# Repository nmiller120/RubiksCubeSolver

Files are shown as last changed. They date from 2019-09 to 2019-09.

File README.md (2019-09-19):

# Automated Rubiks Cube Solver

Ongoing work-in-progress. Goal is to design a system that is able to grab and automatically solve a Rubik's Cube after reading the colors off of the cube via a webcam. A demonstration of the mechanical portion of the build can be seen via the following youtube link: https://www.youtube.com/watch?v=32NWT3KxtNk. A demonstration of the color calibration utility can be seen here: https://www.youtube.com/watch?v=5z36a5fC41Q

## Mechanical Design

Parts were designed in Autodesk Inventor, the cross sections of the parts were copied into Autocad and laid out on a single sheet. The file was exported again this time as a .dxf file. This file was then sent to Ponoko to be lasercut.

The actuators are all standard size hobby servo motors, primarily used in RC cars. They are cheap, fairly powerful, and easy to control.

## Electrical Design

The Arduino acts as the controller for the servo motor assembly. It interfaces with a servo motor driver board to control the 8 servos. The arduino recieves serial commands from the program running on my laptop via USB. These commands are decoded into smaller instructions that are passed down to ther servo driver.

## Software Design

The goal of the project is to have the program start by moving the assembly, showing the layout of the cube to a webcam mounted above. A computer vision algorithm is to be applied to the video feed, detecting the colors on the cube's faces and recording that data into memory. Once all of the faces have been read, the data recorded is to be passed to the Kociemba algorithm. The algorithm outputs instructions on how the cube is to be solved. The AssemblyController module then parses those instructions and determines how each of the given instructions is to be implemented and relays that information to the arduino by commanding the positioning of the assembly's servo motors. A demo of the mechanical assembly working a solution can be seen above, as well as a demo on how the HSV filtering values are calibrated.

I have spent a lot of time commenting and adding documentation to the code for this project. I am trying to keep the code in as readable of condition as possible. Feel free to read through the project files as they may shed light on some of the more of the technical details of the project not covered here. 

Thanks for reading!

### Additional Links:
Kociemba Algorithm: https://github.com/muodov/kociemba  
Open CV Library: https://pypi.org/project/opencv-python/

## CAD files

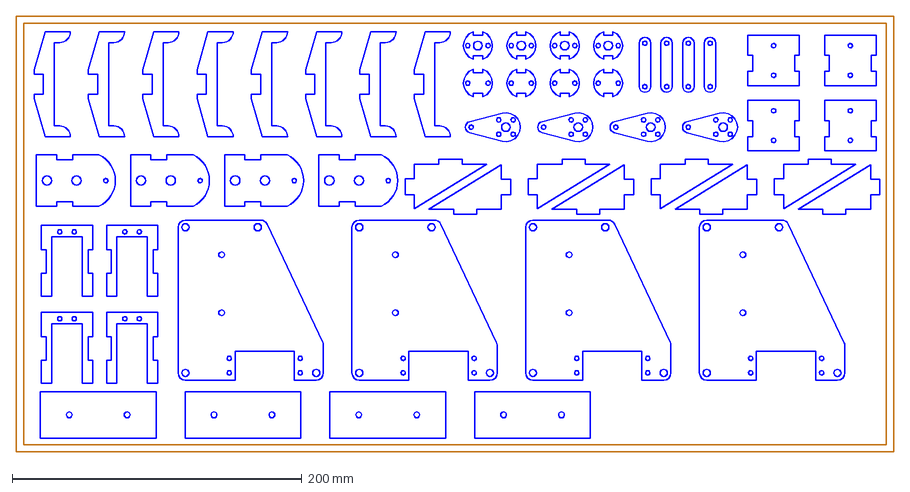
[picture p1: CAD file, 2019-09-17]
Rubiks_Cube_CAD_Design.dxf
606.0 x 301.0 mm

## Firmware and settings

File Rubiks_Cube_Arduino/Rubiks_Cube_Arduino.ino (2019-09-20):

 /**************************************************************************
 Code for the firmware running on the arduino for the rubiks cube project. The arduino acts as a controller for the assembly, 
 taking commands from the PC. The assembly begins in standby mode where it waits for a command.

  - In "Program" mode the arduino waits for the default positions of each of the servo motors to be loaded into the settingArray
  
  - In "calibration" mode the arduino accepts a continuous stream of commands for the positons of each of the servo motors. Unlike in 
  run mode these positions are a value between 0 and 180 allowing the servo motors to sit anywhere in their full range of motion. 
  This mode is used to determine the setpoints to be downloaded in "Program" mode and used in "run" mode.
  
  - In "run" mode the arduino accepts commands of the form "xYxYxY" where x represents any servo motor from 0 to 7 and Y represents a 
  pre-programmed position. This command can have between 2 and 16 characters.
  
  Example of run commands:
    - 012131 (servos 0, 1, and 3 to position 1)
    - 73 (servo 7 to position 3)
    - 4263 (servo 4 to position 2, servo 6 to position 3)

  The servo motors are divided into 2 groups, linear and radial. Linear moves the claws forward and backward, 
  radial servos rotate the claws. Even rows in the settingArray represent linear, odd rows represent radial. 
  
  Position 0, 1, and 2 for radial servos represent 0, 90 and 180 degrees respectively. 
  Positions 0 and 1 represent 45 and 135 degrees respectively. 
 */
#include <Wire.h>
#include <Adafruit_PWMServoDriver.h>

// called this way, it uses the default address 0x40
Adafruit_PWMServoDriver pwm = Adafruit_PWMServoDriver();

// constants defined to use in the calculation of the pulse width sent to the servo motor driver
#define MIN_PULSE_WIDTH       650
#define MAX_PULSE_WIDTH       2350
#define DEFAULT_PULSE_WIDTH   1500
#define FREQUENCY             50

int mode = 0; // 0:standby, 1:program, 2:run
String modeNames[4] = {"standby", "program", "run", "calibration"};
int error_check; // error check to send after programming, program should throw zero, if not there was an error
bool debug = false; // if true, print text to command line
int servoNumber; // servo number, use in run
int servoPos;  // servo position, use in run

char readByte;


int settingArray[8][6]; 
// settingArray: row is servo, col is position, even rows are linear, odd rows are radial
// linear goes 45 pos, 135 pos, 45+ pos, 135+ pos, dummy 90
// radial goes 0 pos, 90 pos, 180 pos, 0+ pos, 90+ pos

void setup(){
  // open serial port, begin communication with the servo driver
  Serial.begin(9600);
  Serial.print(mode);
  pwm.begin();
  pwm.setPWMFreq(FREQUENCY);  // Analog servos run at ~60 Hz update
}

void loop() {
  // main loop, 4 different modes of operation
  while (Serial.available()==0){}// wait for serial data
  if (mode == 2) {run_mode();} // if in run, run run 
  else if (mode == 3) {calibration();} // if in calibration mode, run calibration
  else if (mode == 0){standby();} //if in standby run standby
  else if(mode == 1){program();} // if in program mode run program 
}

void calibration(){
  /*
     Function reads a semi-continuous stream of data. Each calibration command is coded in ASCII text and is of the form
     1.x.x.x.x.x.x where 1 signals the start of a new command and each x is an integer between 0 and 180. The following code 
     parses those commands and writes them out to the motor controller using the setPWM() function. If a value of -10 is sent 
     to the arduino the assembly returns to standby mode
  */
  while(Serial.available()){
    int readIN = Serial.parseInt();
    if (readIN == 1){
      int servoPos[8];
      for(int i=0; i<8; i++){
        servoPos[i] = Serial.parseInt();
        pwm.setPWM(i, 0, pulseWidth(servoPos[i])); 
        }
      }
    else if (readIN == -10){changeMode(0);}
    }
  }

void run_mode(){
  /*    
    Function reads coded commands from the serial port and moves the motors to match the described positions. Motors 
    That aren't addressed in the command don't move. If the arduino recieves an invalid input the program returns to standby
     
    run mode serial commands: first character refers to the servo to control,
    2nd character refers to the position, ie, "0121" means servo 0 position 1, servo 2
    position 1. The positions are defined during the program phase, which is implemented
    in the code for the __init__() method of this class
  */
  int servoNumber;
  int servoPosition;

  while (Serial.available() < 2) {}
  servoNumber = Serial.read() - '0'; 
  servoPosition = Serial.read() - '0';
  
  if (servoNumber > 7 || servoNumber < 0) {changeMode(0);} // change mode if servo addressed is not in range
  
  if (mode == 2){ // if still in run mode, move servos and change output
    if (debug) {
      Serial.print('\n');
      Serial.print(servoNumber); Serial.print(' '); Serial.print(servoPosition);
      }
    int angle = settingArray[servoNumber][servoPosition];
    pwm.setPWM(servoNumber, 0, pulseWidth(angle));
    }
  }
  
void program(){
  /*
   * This function is how the default position values are loaded to the arduino. The software running on the PC sends the positioning 
   * data as a stream of bytes (ie. 180 is transmitted as a single byte with hex value 0xB4). These values are loaded into the 
   * settingArray. The setting array is a 2d array. Even rows in the array are controlling linear motion, odd rows in the array are 
   * controlling radial motion. 
   *
   * Format of linear = [deg45, deg135, 0, 0, 0, 90] // the 90 degree values act as an error check of the instruction
   * Format of radial = [deg0, deg90, deg180, 0, deg90+, deg180+] deg90+ and deg180+ are slightly more agressive turns to help 
   * allignment of the cube face when turning a side.
   * 
   * Automatically goes back to standby mode after program settings are recieved
   */
  
  while (Serial.available()){
      delay(1000); //give the buffer time to fill
      for (int i=0; i<8; i++){
        for (int j=0; j<6; j++){
          settingArray[i][j] = Serial.read(); // if in program mode load settingArray with data from serial buffer
          }
        }
      
        // error check = 0
        if (settingArray[0][5]==90 && settingArray[2][5]==90 && settingArray[4][5]==90 && settingArray[6][5]==90){error_check = true;} 
   
        if (debug == true){
          Serial.println("Recieved data..."); 
          for (int i=0; i<8; i++){
            for (int j=0; j<6; j++){
              Serial.print(settingArray[i][j]); // if in program mode load setting array with data from serial buffer
              Serial.print(',');               
              }
            Serial.print('\n');
          }
          if (error_check){Serial.println("No Error");} else {Serial.println("Error");}
        }   
        else {
          if (!debug && error_check){Serial.print('y');}
          else {Serial.print('n');}
          }
        changeMode(0);
  }
}

void standby(){
  /*
   * Standby mode waits for a mode change command. Command is a 5 character ascii string. Debug mode can also be toggled in standby. 
   * This just sends debug messsages to the serial port along with the acnowlegments that are sent when debug mode is off. 
   */
  
  char modeSelect[8] = "";
      Serial.readBytes(modeSelect, 5);
      if (!strcmp(modeSelect, "progm")){changeMode(1);} // set to program mode if "program" was recieved in the serial buffer
      else if (!strcmp(modeSelect, "runmd")){changeMode(2);} // set to run if "run" was recieved in the serial buffer
      else if (!strcmp(modeSelect, "check")){checkData();}
      else if (!strcmp(modeSelect, "calib")){changeMode(3);}
      
      else if (!strcmp(modeSelect, "debug")){ // toggle debugging
          if (debug) {
            debug = false;
            changeMode(0);
            } 
           else if (!debug){
              debug = true;
              Serial.print('\n');
              Serial.println("Debugging");
           }
        }  
      else mode = 0;
      while(Serial.available()){Serial.read();}//flush the port
}

void checkData(){
  /*
   * If a check command is recieved in standby mode, this function will write the currently stored settingArray to the serial port
   */
  Serial.println("Recieved data..."); 
  for (int i=0; i<8; i++){
    for (int j=0; j<6; j++){
      Serial.print(settingArray[i][j]); // if in program mode load setting array with data from serial buffer
      Serial.print(',');               
    }
    Serial.print('\n');
  }
  }

void changeMode(int newMode){
  // function invoked when a changemode command is recieved at the serial port
  mode = newMode;
  if (debug == true) {
    Serial.print("In ");
    Serial.print(modeNames[mode]);
    Serial.println(" mode");
    }
  else {Serial.print(mode);}
  }

int pulseWidth(int angle){
  // calculates the pulse width value needed to achieve the desired angle of the servo motor
  int pulse_wide, analog_value;
  pulse_wide   = map(angle, 0, 180, MIN_PULSE_WIDTH, MAX_PULSE_WIDTH);
  analog_value = int(float(pulse_wide) / 1000000 * FREQUENCY * 4096);
  return analog_value;
}

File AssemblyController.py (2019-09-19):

# Module defines a single class AssemblyController which handles all communication
# with the servo assembly.

# When solving the cube, first the controller object is created, then the kociemba
# SOLUTION string is passed to the class method kociemba(). This method parses
# the solution string and sends the arduino controlling the assembly a series of
# instruction codes describing the positions of the servo motors needed to solve
# the puzzle. The other class methods are all public and can be called as needed.

# run mode serial commands: first character refers to the servo to control,
# 2nd character refers to the position, ie, "0121" means servo 0 position 1, servo 2
# position 1. The positions are defined during the program phase, which is implemented
# in the code for the __init__() method of this class

import serial
import time

class AssemblyController():

    __Serial = None # serial port object
    __delay = 0.5 # time the system waits for the servomotors to get into position
    # before sending the next command

    def __init__(self):

        # create serial port obj.
        self.__Serial = serial.Serial('COM3',9600, timeout = 1)
        Serial = self.__Serial
        while Serial.in_waiting == 0: # wait for data to arrive at the port
            pass

        print(Serial.read()) # print byte from port

        Serial.write("progm".encode('utf-8')) # set arduino to program mode
        print(Serial.read()) # read response from arduino

         # load servo default position values from csv file
        csv_file = "servos.csv"
        aFile = open(csv_file, 'r') # open csv file in read mode

        toSend = ""
        for line in aFile:
            line = line.strip()
            csv_line = line.split(",")
            for x in range(6):
                toSend += chr(int(csv_line[x])) # read csv values into 'toSend'

        Serial.write(toSend) # write 'toSend' data to arduino

        while (Serial.in_waiting==0): # wait for response
            pass

        while (Serial.in_waiting): # read response
            print(Serial.read()) # print response

        Serial.write("runmd".encode("utf-8"))
        print(Serial.read())

    def rightCCW(self):
        # method rotates the entire cube about the right axis CCW
        delay = self.__delay
        Serial = self.__Serial
        self.all_engaged()
        time.sleep(delay)
        Serial.write('2161') #1
        time.sleep(delay)
        Serial.write('7131') #2
        time.sleep(delay)
        Serial.write('2060') #3
        time.sleep(delay)
        Serial.write('0141') #4
        time.sleep(delay)
        Serial.write('3072') #5
        time.sleep(delay)
        Serial.write('0040') #6
        time.sleep(delay)
        Serial.write('61') #7
        time.sleep(delay)
        Serial.write('70') #8
        time.sleep(delay*1.5)
        Serial.write('60') #9
        time.sleep(delay)

    def rightCW(self):
        # method rotates the entire cube about the right axis clockwise
        delay = self.__delay
        Serial = self.__Serial
        self.all_engaged()
        time.sleep(delay)
        Serial.write('2161') #1
        time.sleep(delay)
        Serial.write('7131') #2
        time.sleep(delay)
        Serial.write('2060') #3
        time.sleep(delay)
        Serial.write('0141') #4
        time.sleep(delay)
        Serial.write('3270') #5
        time.sleep(delay)
        Serial.write('0040') #6
        time.sleep(delay)
        Serial.write('21') #7
        time.sleep(delay)
        Serial.write('30') #8
        time.sleep(delay*1.5)
        Serial.write('20') #9
        time.sleep(delay)

    def frontCCW(self):
        # method rotates the entire cube about the front axis counter-clockwise
        delay = self.__delay
        Serial = self.__Serial
        self.all_engaged()
        time.sleep(delay)
        Serial.write('0141') #1
        time.sleep(delay)
        Serial.write('1151') #2
        time.sleep(delay)
        Serial.write('0040') #3
        time.sleep(delay)
        Serial.write('6121') #4
        time.sleep(delay)
        Serial.write('1052') #5
        time.sleep(delay)
        Serial.write('2060') #6
        time.sleep(delay)
        Serial.write('41') #7
        time.sleep(delay)
        Serial.write('50') #8
        time.sleep(delay*1.5)
        Serial.write('40') #9
        time.sleep(delay)

    def frontCW(self):
        # method rotates the entire cube about the front axis clockwise
        delay = self.__delay
        Serial = self.__Serial
        self.all_engaged()
        time.sleep(delay)
        Serial.write('0141') #1
        time.sleep(delay)
        Serial.write('1151') #2
        time.sleep(delay)
        Serial.write('0040') #3
        time.sleep(delay)
        Serial.write('6121') #4
        time.sleep(delay)
        Serial.write('1250') #5
        time.sleep(delay)
        Serial.write('2060') #6
        time.sleep(delay)
        Serial.write('01') #7
        time.sleep(delay)
        Serial.write('10') #8
        time.sleep(delay*1.5)
        Serial.write('00') #9
        time.sleep(delay)

    def all_retract(self):
        # method retracts all claws
        instruction = '0110213041506170'
        self.__Serial.write(instruction)

    def all_engaged(self):
        # method extends all claws
        instruction = '0010203040506070'
        self.__Serial.write(instruction)

    def kociemba(self, kociemba_string):
        # method implements the kociemba solution
        # Example of kociemba string:
        # "R' D2 R' U2 R F2 D B2 U' R F' U R2 D L2 D' B2 R2 B2 U' B2"

        sides = ['F', 'R', 'B', 'L', 'U', 'D']
        inst = kociemba_string.split(' ')
        size = len(inst)
        print(size)

        # for each instruction in array
        for x in range(size):
            rotation = None

            # if instruction has one character, mark for clockwise rotation
            if len(inst[x]) == 1:
                rotation = "CW"

            # if instruction is followed by a single quote, mark for counter
            # clockwise rotation
            elif inst[x][1] == '\'':
                rotation = "CCW"

            # if instruction is followed by a 2 mark for 2 clockwise rotations
            elif inst[x][1] == '2':
                rotation = "2CW"

            # if the instruction is for a face that is not on the top or bottom
            # turn the given face according to the direction found above
            for y in range(4):
                if inst[x][0] == sides[y]:
                    self.turn_face(y, rotation)

            # if the instruction is for the top face, turn the cube ccw about the
            # right axis, then rotate the face in the front position. After the front
            # face is turned, rotate the cube back to the default position.
            if inst[x][0] == 'U':
                self.rightCCW()
                self.turn_face(0, rotation)
                self.rightCW()
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

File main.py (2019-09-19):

# Rubik's Cube Solver Project
# Nick Miller
# Last Update: Feb, 2018

import RubiksGUIs as gui # contains classes used for the calibration gui
import AssemblyController as cubes # implements the lower level control of the
# rubiks cube, moves the servo assembly
import Mask as overlay # implements image filtering
from tkinter import * # library for implementing guis
import cv2 # library for implementing computer vision, has algorithms for color
# image processing and api for reading data from webcams and image files
import serial # library for implementing the serial interface with the arduino
import time # used primarily in this project to implement wait functions
import kociemba # Implements the kociemba algorithm, given a cube map it provides
# a function that will return a string representing the instructions to solve the
# rubiks cube.

def workKociembaSolution(cubeStr, waitTime):
    # Method used to solve the cube with a hardcoded cube map, cubeStr is the
    # cube map, waitTime is the time to delay before the assembly grabs the cube

    cubeStr = convertInput(cubeStr, "URF") # convert from position reference to color reference
    solution = kociemba.solve(cubeStr) # get solution string from kociemba algorithm
    control = cubes.AssemblyController() # create a control object
    control.all_retract() # retract all arms
    time.sleep(waitTime) # wait some time for the cube to get into position
    control.all_engaged() # engage claws
    control.kociemba(solution) # execute instruction string
    time.sleep(0.5) # wait
    control.all_retract() # release cube

def convertInput(kociembaIN, toWhat):
    # the kociemba algorithm accepts a general cube map string that is agnostic to
    # what color the faces are. In this formatting the sides are labeled as 'u', 'r'
    # 'f', 'd', 'l' and, 'b' for up, right, down, front, down, left, and back. This
    # method is used to convert between kociemba's general cube mapping and a cube
    # mapping based on the colors of the faces.

    # The functions argument kociembaIN is a general cube map string,
    # toWhat is a string representing what the desired reference, color or orientation.
    # Orientation based reference is denoted by passing the string "URF" (up, right front)
    # and color based reference is denoted by passing the string "WBR" (white, blue, red)

    replace = 'WBRYGO'
    replace_with = 'URFDLB'

    if toWhat is 'URF':
        replace = 'WBRYGO'
        replace_with = 'URFDLB'

    elif toWhat is 'WBR':
        replace = 'URFDLB'
        replace_with = 'WBRYGO'

    transtab = {ord(x): y for (x, y) in zip(replace, replace_with)}
    print(kociembaIN)
    return kociembaIN.translate(transtab)

def servoCalibration():
    # This function implements positioning calibration for the project.
    # The intended use is to move the servo motors using the sliders on the GUI to
    # and to record by hand the desired positioning of the servo motors.

    # These default settings are to be recorded in the file servos.csv which then
    # provides configuration parameters for the project when sending commands to
    # the servo assembly in "run" mode.

    ser = serial.Serial('COM3',9600)
    time.sleep(2);
    ser.write("calib".encode("utf-8"))
    time.sleep(1);

    root = Tk()
    root.title("Main Window")
    root.geometry('600x700')
    setup_app = gui.Setup_Servo_Window(root)

    for x in range(4):
        y = x*2
        setup_app.scale_widgets[y].set(50)

    while True:
        try:
            setup_app.update_idletasks()
            setup_app.update()
            serial_str = "1."

            for x in range(8):
                text = str(setup_app.scale_widgets[x].get())
                serial_str += text + "."

            serial_str += "\n"
            ser.write(serial_str)

        except:
            while (ser.in_waiting):
                print(ser.read(), end='')
            break

def colorCalibration(capSource = None):
    # Color Calibration gui, this function implements a system for calibrating
    # the color filter settings for the computer vision portion of the project.
    # Sliders allow the user to set the min and max HSV values for the filter for
    # each of the 6 cube face colors as well as filters to remove background colors.
    #
    # The argument capSource is an integer representing the desired video capture source,
    # If there are multiple webcams connected to your pc you select them with the
    # integer. The default value of None opens an image file "rcube.jpeg".

    root = Tk()
    root.title("Main Window")
    root.geometry('600x700')

    frame = None
    if capSource == None:
        frame = cv2.imread("rcube.jpg")

    else:

        cap = cv2.VideoCapture(capSource)
        ret, frame = cap.read()

    mask = overlay.Mask()

    # Create Main Window
    setup_app = gui.Setup_Color_Window(root)

    # begin loop, end when setup is complete
    while not setup_app.is_complete():
        try:
            #pull image from feed
            if cap != None:
                ret, frame = cap.read()

            #add mask overlay to image
            img = mask.parse_cap(frame, setup_app.get_lower_range(), setup_app.get_upper_range(), setup_app.is_exclusive())

            #update setup app
            setup_app.update_idletasks()
            setup_app.update()

            #display image
            cv2.imshow("Frame", img)

        except TclError:
            cap.release()
            cv2.destroyAllWindows()
            break


    #if "finished" is pressed close windows
    if setup_app.is_complete():

        root.destroy()
        cv2.destroyAllWindows()

def main():
    # servoCalibration()
    # workKociembaSolution("WYOYWRGBBRGBOBGWYWROWORYROOBGGWYBYWGORYBGWGBYYGBWORRRO",4.0)
    colorCalibration(0)

if __name__ == '__main__':
    main()


##References:
##      http://docs.opencv.org/3.0-beta/doc/py_tutorials/py_core/py_basic_ops/py_basic_ops.html
##      Tutorial 5

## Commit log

2019-09-17 Added cad files to design folder
    [Rubiks_Cube_CAD_Design.dxf]
2019-09-19 removed broken code, added more comments.
    [colors.csv]
2019-09-19 correcting typos, fixed bug on color calibration gui
    [AssemblyController.py, Mask.py, RubiksGUIs.py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]
2019-09-19 updated comments in arduino code
